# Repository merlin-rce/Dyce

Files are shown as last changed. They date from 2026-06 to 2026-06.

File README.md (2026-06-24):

<div align="center">

DYCE · why roll the same old dice?

**A premium, round, open-source electronic die.** 
Spin the ring, the circular screen
charges up, rolls a number and lands on it. ESP32-S3 · custom PCB · weighted enclosure · USB-C.

[**Live simulator**](https://merlin-rce.tech/Dyce) · [**Gallery**](Media/Gallery.md) · [**Firmware**](Firmware/) · [**Contribute**](CONTRIBUTING.md)

</div>

---

<div align="center">
  Dyce irl demo
</div>

## What it is

- A **round** die that feels like a product,
the screen sits inside a **ring encoder** and stays still while you spin the ring.
- **Custom PCB** (ESP32-S3, GC9A01 round TFT, USB-C, Li-ion charge), hand-soldered, **powered up first try**.
- **100% offline.** Rolls use the ESP32 hardware RNG (`esp_random`) with rejection sampling, so every face is exactly equally likely.
- First real hardware project by a Swiss electronics student, built in the open as a learning log.

## How to Use

- **Spin right** → the ring charges, then rolls and reveals a number.
- **Spin left** → change the odds: `1 in 2 / 5 / 10 / 50 / 99`, plus a **Contact** qr code of the repo.
- **Pause around ⅔** → a little easter egg ;)

Try it all in the **[live simulator](https://merlin-rce.tech/Dyce)**, no hardware needed.

## Build the firmware

C++ / [PlatformIO](https://platformio.org/), target ESP32-S3-WROOM-1.

```bash
git clone https://github.com/merlin-rce/Dyce.git

cd Dyce/Firmware

pio run -t upload      # build & flash
```

Wiring & schematic: [`PCB/`](PCB/) · code overview: [`Firmware/`](Firmware/).

## Print & build the hardware

Everything you need to make your own DYCE is in the repo:

- **3D-printed enclosure** → [`3D Files/`](3D%20Files/) with all the STL parts (body, encoder ring, screen holder, PCB cover, button cap).
- **PCB** → [`PCB/`](PCB/) with the [schematic](PCB/Schematics.pdf) plus ready-to-order **[Gerber & drill files](PCB/Fabrication/)** you can send to any board house (JLCPCB, PCBWay, etc.).

### Edit the 3D model (Onshape)

The full parametric CAD lives on Onshape:

**[Open the DYCE CAD model](https://cad.onshape.com/documents/9054087476b99494dbf8772b/w/43f19220b97c6495800911b1/e/0047a7d77bd93aa77dba2c59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)**

Want to tweak a part or design your own variation? **[Ask me for access](https://github.com/merlin-rce/Dyce/issues)**, then **make your own copy** (Onshape, *Make a copy*) so you can edit freely without touching the original.

## Make it your own

DYCE is **finished, but not closed.** Everything here is open so you can **build one,
tweak it, and make it better.** Flash a different animation, add new odds, rethink the
attract loop, redesign the enclosure, or fork the whole thing into your own gadget.
That's exactly what it's here for. If you make a variation, I'd love to see it.

> **A full step-by-step [Instructables](https://www.instructables.com/) build guide is
> coming soon**, every part, every solder joint, start to finish, so anyone can make
> their own. Watch this repo to catch it when it drops.

## a bit of honesty

quick honest part: im 17 and still a student, and this started as a school project. im a beginner and i learn as i go, thats honestly the whole point of this for me. i put it open source because i genuinely want people to look at it, give me feedback and teach me things, im always down to learn and get better.

the hardware is fully me: the pcb, the schematic, picking the parts, the cad, the soldering and all the debugging that comes with it. pretty proud of that part. the web simulator was mostly built with claude (ai) since my react/html is still basic. for the firmware i use ai to help me too, but as a beginner i really try to understand what im doing and learn from it, not just blindly copy paste.

and if you notice theres barely any commits, its just cause im still new to github and kinda pushed everything at once. still learning that part too

## Contribute

This is a learning project and **feedback / PRs are genuinely welcome**: schematic
nitpicks, firmware cleanups, enclosure ideas, anything. Start with **[CONTRIBUTING.md](CONTRIBUTING.md)**
or open an [issue](https://github.com/merlin-rce/Dyce/issues).

## Status

**Project finished**, built, working, and documented in the open.

| Hardware | Firmware | Enclosure |
|---|---|---|
| Working | Done | Done (could be better) |

## License

Firmware & code: **MIT** (see [`LICENSE`](LICENSE)).
Hardware and docs are intended as **CERN-OHL-S v2** and **CC BY-SA 4.0** respectively.
*To be confirmed before final.*

<div align="center">
  Built in Switzerland by <a href="https://github.com/merlin-rce">@merlin-rce</a> · learning as I go.
</div>

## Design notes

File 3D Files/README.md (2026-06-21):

# DYCE 3D printed parts
<div align="center">
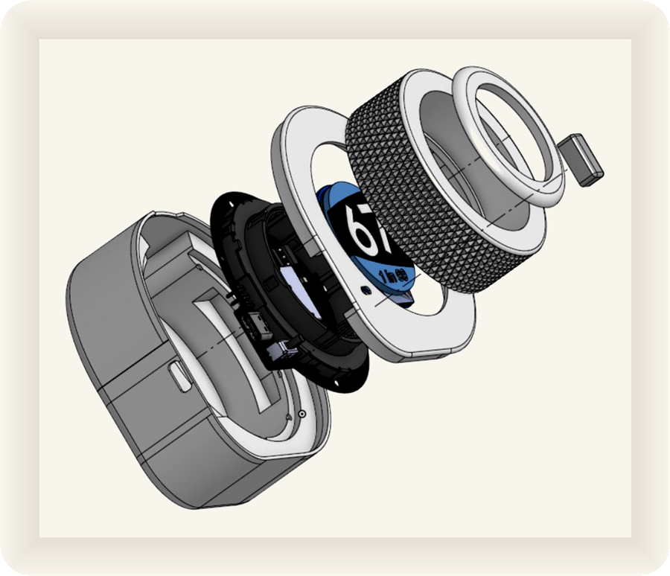
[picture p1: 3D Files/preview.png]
DYCE 3D parts

</div>

---

The full enclosure, ready to print (STL, v5).

| File | Part |
|---|---|
| [`Bottom.stl`](Bottom.stl) | main body / base |
| [`Encoder-ring.stl`](Encoder-ring.stl) | the ring you spin (encoder) |
| [`Screen-holder.stl`](Screen-holder.stl) | holds the round GC9A01 screen |
| [`PCB-cover.stl`](PCB-cover.stl) | cover over the PCB |
| [`Button-cap.stl`](Button-cap.stl) | cap for the side power button |

## Edit the model

These STLs are exported from the parametric CAD on **Onshape**:

**[Open the DYCE CAD model](https://cad.onshape.com/documents/9054087476b99494dbf8772b/w/43f19220b97c6495800911b1/e/0047a7d77bd93aa77dba2c59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)**

To change a part or make a variation, **ask me for access**, then **make your own copy**
(Onshape, *Make a copy*) and edit freely. The original stays untouched.

## Printing

All five parts are FDM-friendly and print without drama, no exotic settings needed.

**Tested print:** I printed the whole set in **matte PLA** on a **Bambu Lab A1**, straight
from **Bambu Studio's standard 0.20 mm quality preset** with no custom tuning, and it came
out clean. PLA (matte looks great) or PETG both work well.

| Setting | What I used |
|---|---|
| Printer | Bambu Lab A1 |
| Material | Matte PLA |
| Profile | Bambu Studio · 0.20 mm Standard (default) |
| Supports | only where overhangs need them |

> **Coming soon on [MakerWorld](https://makerworld.com/)**, ready-to-print profiles,
> one click from your slicer.

Full orientation, support placement and the rest of the assembly will be covered in the
step-by-step **Instructables** build guide (coming soon).

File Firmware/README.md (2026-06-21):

<div align="center">

# DYCE Firmware

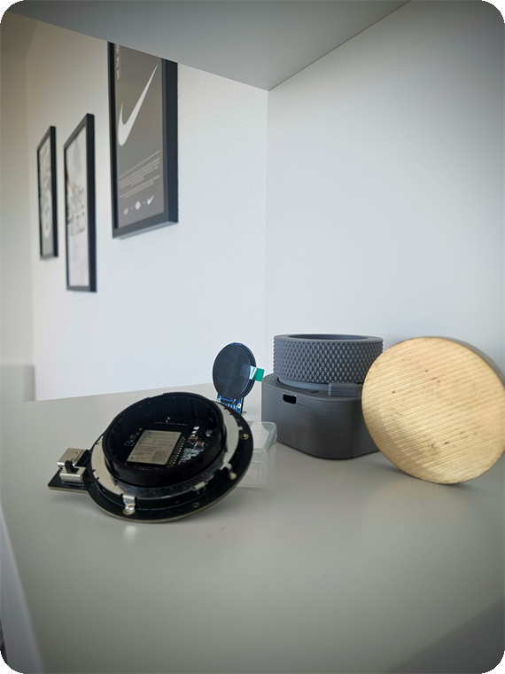
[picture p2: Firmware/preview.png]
DYCE screen


C++ / [PlatformIO](https://platformio.org/) · ESP32-S3-WROOM-1 · GC9A01 round TFT · **100% offline**

</div>

---

## Build & flash

```bash
cd Firmware
pio run -t upload      # build & flash
pio device monitor     # serial @ 115200
```

Display & encoder pins live in [`platformio.ini`](platformio.ini) (TFT_eSPI reads them at compile time).

## Layout

| File | What it does |
|---|---|
| [`src/main.cpp`](src/main.cpp) | setup / loop, wires the encoder to the game |
| [`src/dice.cpp`](src/dice.cpp) | game state machine (intro · attract · charge · reveal) |
| [`src/ui.cpp`](src/ui.cpp) | all rendering on the round screen (sprite buffer) |
| [`src/rng.cpp`](src/rng.cpp) | fair rolls (ESP32 hardware RNG + rejection sampling) |
| [`lib/Encoder_lib/`](lib/Encoder_lib/) | the ring rotary-encoder driver |
| [`include/config.h`](include/config.h) | all the timings, colors and tunables in one place |
| `src/logo.h · icon.h · qr_image.h` | embedded images (intro logo, the "D", contact QR) |

## Make it yours

Most of the feel lives in [`config.h`](include/config.h) and [`ui.cpp`](src/ui.cpp): change
the odds, the colors, the animations or the attract tips and reflash. PRs and forks welcome.

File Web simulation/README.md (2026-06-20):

# DYCE — web simulator

A faithful browser simulator of the DYCE electronic dice, to show the project
without the hardware. It's a 1:1 port of the firmware: the same state machine
(`dice.cpp`) and the same rendering (`ui.cpp`), drawn on a `<canvas>`.

**Live:** intended for `merlin-rce.tech/Dyce`

## Controls
- **Scroll** on the dice = turn the ring encoder
  - scroll **up** → charge the ring & roll
  - scroll **down** → change the difficulty category (… 99 → Contact QR)
  - pause around **2/3** of the ring → unlock the hidden secret (67)
- Click **Power** = the device general switch (on / off)
- (bonus) arrow keys also work

## Run locally
It's a static site — just open `index.html`, or serve the folder:
```bash
python -m http.server      # then visit http://localhost:8000
```

## Deploy
Static hosting. Copy this folder to your web root under `/DYCE`. It needs
internet only for the Montserrat web font (everything else is local).

## Files
| File | Role |
|---|---|
| `index.html` | the page (device mockup + power switch) |
| `style.css` | minimalist styling |
| `app.js` | the simulator (ported game logic + canvas renderer) |
| `assets/logo.png` | the logo (dark theme) |
| `assets/qr.png` | the Contact QR code |

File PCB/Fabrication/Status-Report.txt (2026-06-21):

Output: NC Drill Files
Type  : NC Drill
From  : PCB Document [PCB.PcbDoc]
   Generated File[PCB-RoundHoles.TXT]
   Generated File[PCB-SlotHoles.TXT]
   Generated File[PCB.DRL]
   Generated File[PCB.LDP]
   Generated File[PCB.DRR]

Files Generated   : 5
Documents Printed : 0

Finished Output Generation At 08:49:06 On 02.04.2026

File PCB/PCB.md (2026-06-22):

# DYCE PCB
---

The custom board that runs DYCE: a single round PCB sized to sit behind the screen,
hand-soldered and **powered up first try**. **100% offline**: no Wi-Fi, no radios used
for the game, randomness comes straight from the ESP32 hardware RNG.
<div align="center">
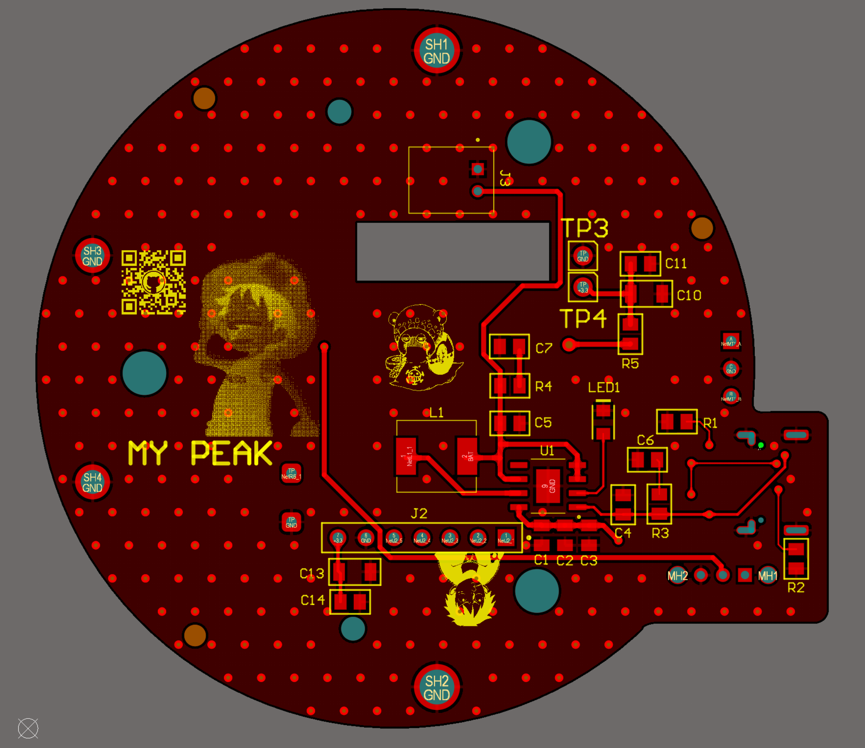
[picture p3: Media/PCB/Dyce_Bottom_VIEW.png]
DYCE Bottom VIEW

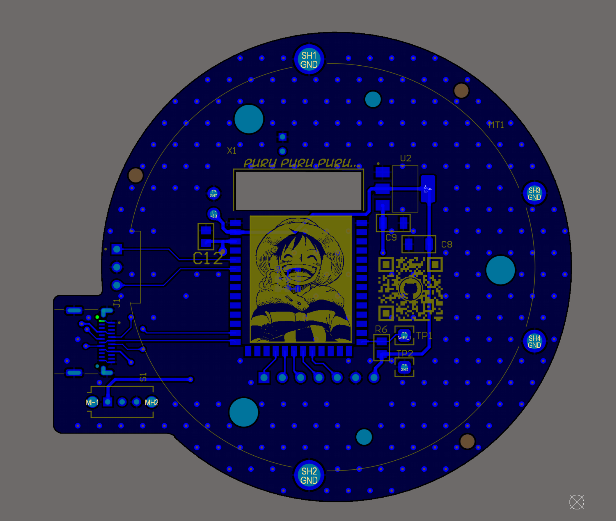
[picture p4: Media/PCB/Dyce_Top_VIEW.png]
DYCE Top VIEW

</div>

## What's on it

- **MCU**: ESP32-S3-WROOM-1 (N16R8, 16 MB flash + 8 MB PSRAM)
- **Display**: GC9A01 1.28″ **round** 240×240 TFT, SPI
- **Input**: ring **rotary encoder** (the screen stays still while you spin the ring)
- **Power**: USB-C, Li-ion charging, side power button

## Pinout (firmware)

These match the firmware. Display pins are set at compile time in
[`../Firmware/platformio.ini`](../Firmware/platformio.ini), the encoder in
[`../Firmware/include/config.h`](../Firmware/include/config.h).

| Signal | GPIO | Notes |
|---|---|---|
| TFT SCLK | 14 | display SPI clock |
| TFT MOSI (SDA) | 13 | display SPI data |
| TFT DC | 12 | data / command |
| TFT CS | 11 | chip select |
| TFT RST | 10 | reset |
| TFT MISO | n/a | unused |
| Encoder A | 6 | `PIN_ENC_A` |
| Encoder B | 5 | `PIN_ENC_B` |

> No backlight pin, the GC9A01 module is driven directly. Flip the encoder direction
> with `ENC_DIR` in `config.h` if it reads backwards.

## Files

- **[`Schematics.pdf`](Schematics.pdf)**: full schematic.
- **[`Fabrication/`](Fabrication/)**: everything a board house needs.
  - `Gerber/`: copper, mask, silk, outline (`.GTL/.GBL/.GTS/.GBS/.GTO/.GBO/.GM`)
  - `Drill/`: NC drill files (round + slot holes)

## Order your own

1. Zip the contents of [`Fabrication/`](Fabrication/) (Gerber + Drill).
2. Upload to any board house: **[JLCPCB](https://jlcpcb.com/)**, **[PCBWay](https://www.pcbway.com/)**, etc.
3. Defaults are fine (1.6 mm, HASL or ENIG). The round outline is in the Gerbers, so no extra setup needed.

A full step-by-step assembly walk-through (board, screen, enclosure) is coming with the
**Instructables** guide. Found an issue or improved the layout?
[Open an issue](https://github.com/merlin-rce/Dyce/issues), schematic nitpicks welcome.

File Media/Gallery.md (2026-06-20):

# Gallery

All the visuals of **DYCE** — 3D renders, the PCB, and build photos.

> Live simulator: **[merlin-rce.tech/Dyce](https://merlin-rce.tech/Dyce)**

## Renders

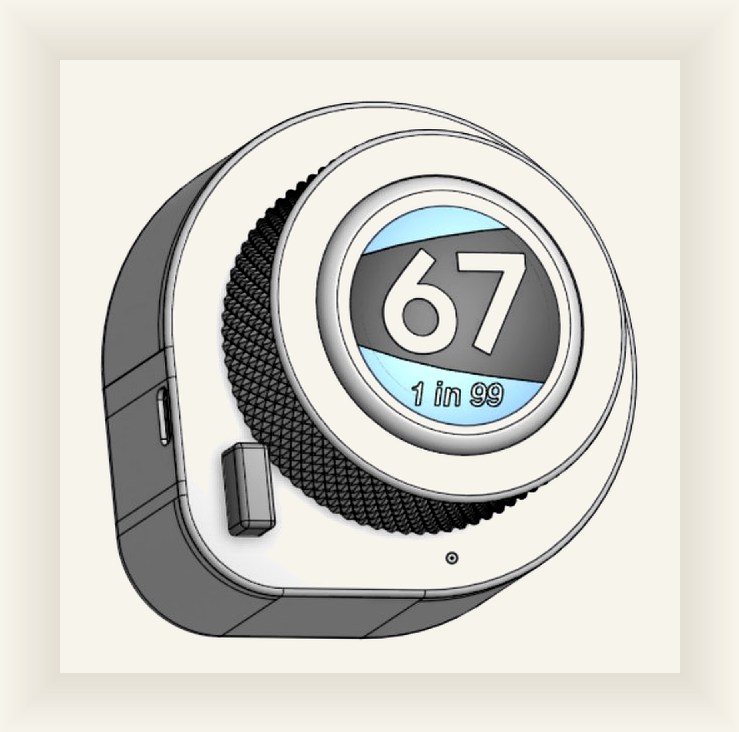
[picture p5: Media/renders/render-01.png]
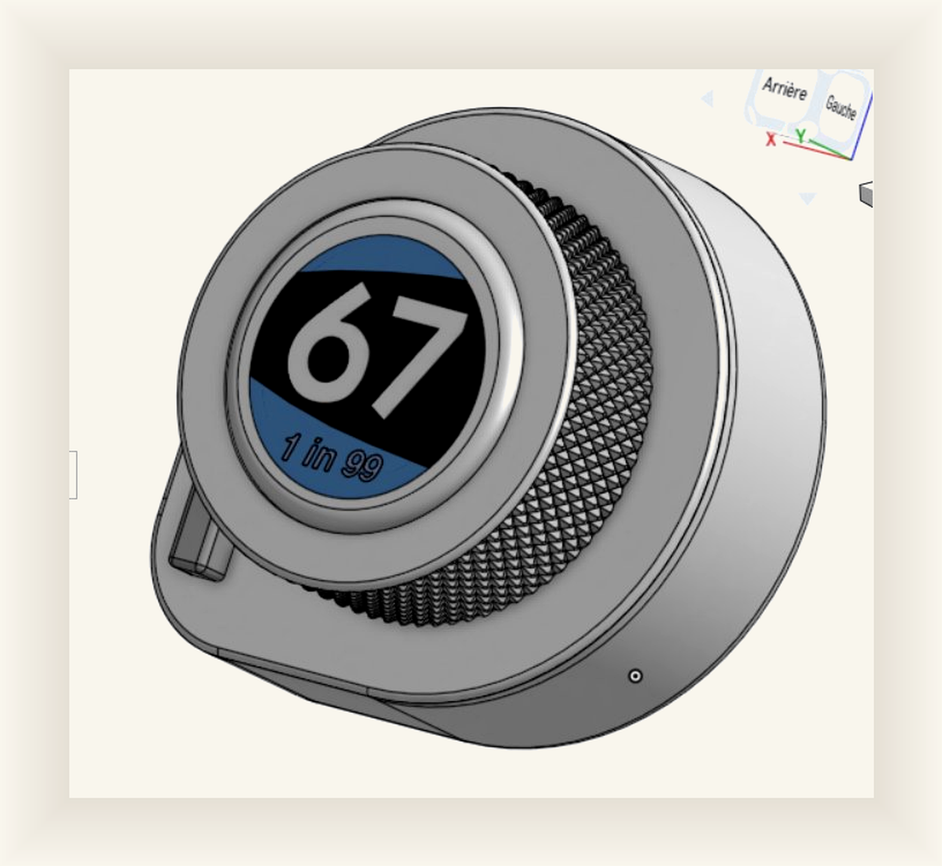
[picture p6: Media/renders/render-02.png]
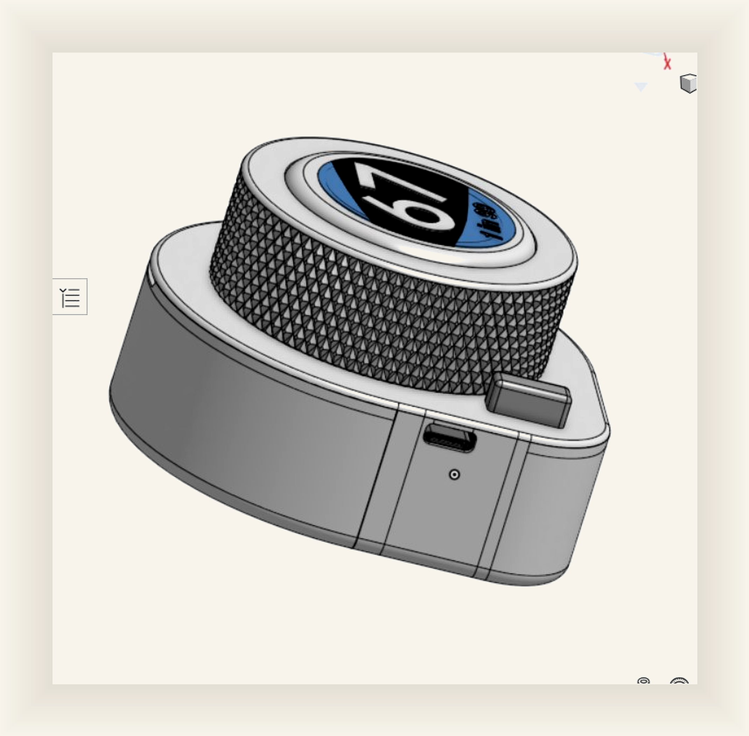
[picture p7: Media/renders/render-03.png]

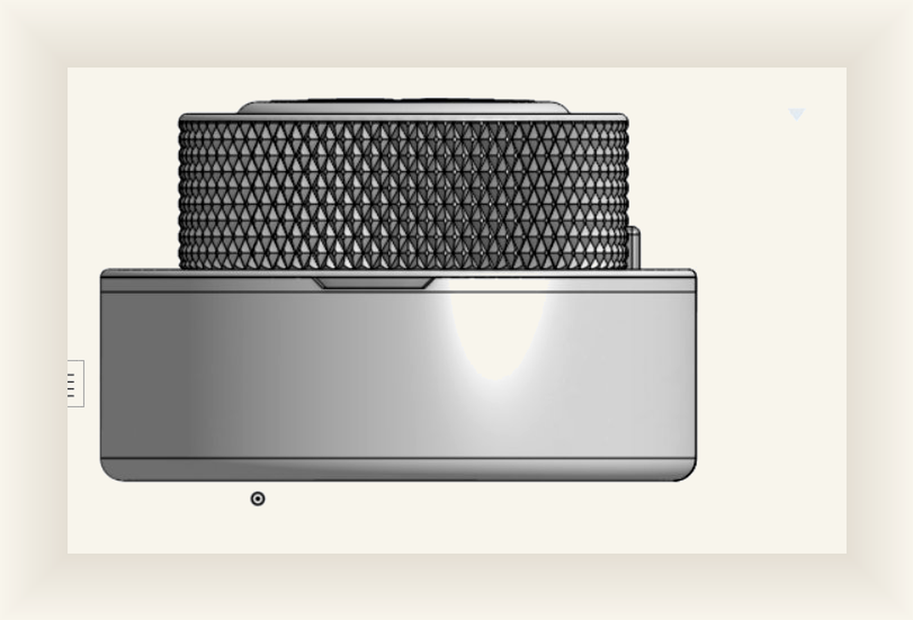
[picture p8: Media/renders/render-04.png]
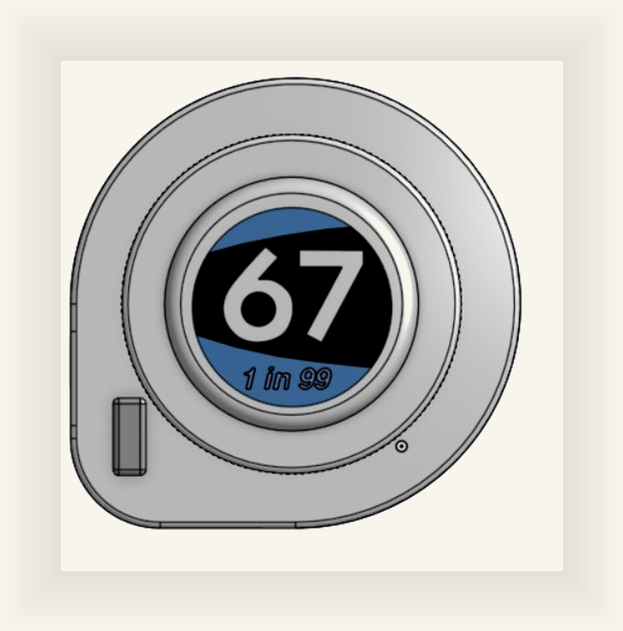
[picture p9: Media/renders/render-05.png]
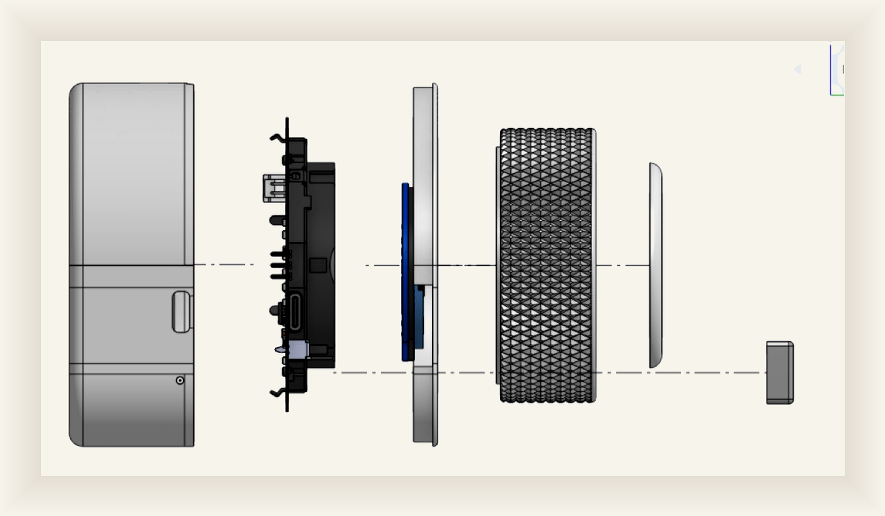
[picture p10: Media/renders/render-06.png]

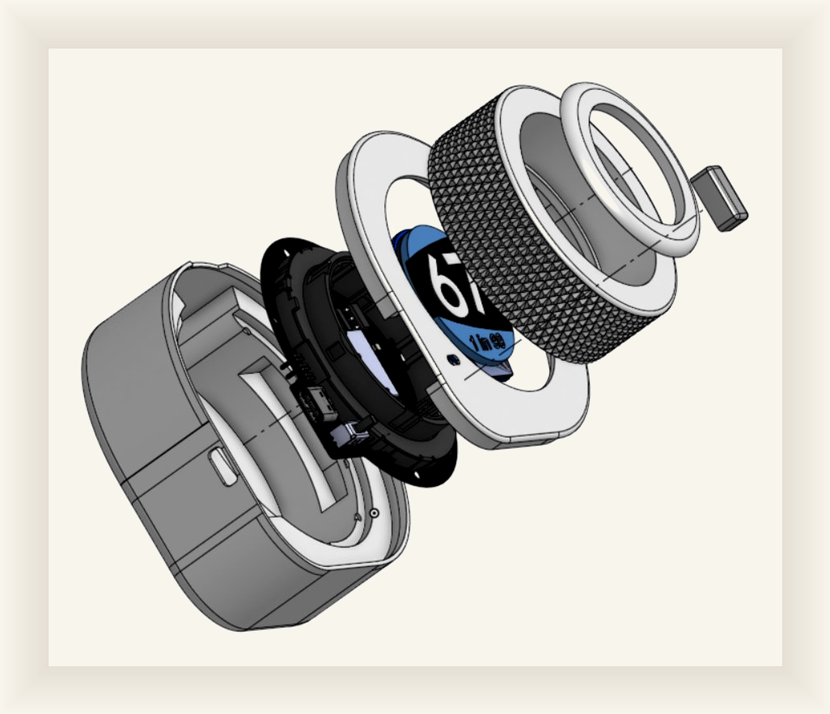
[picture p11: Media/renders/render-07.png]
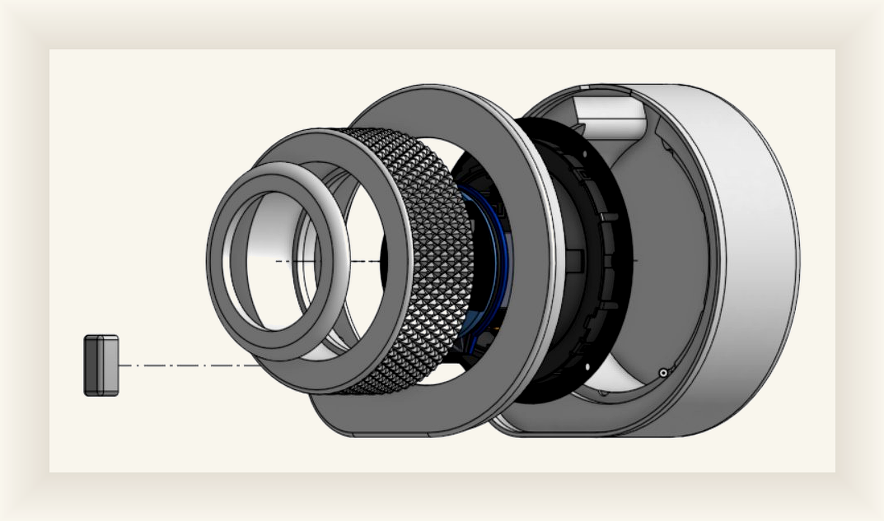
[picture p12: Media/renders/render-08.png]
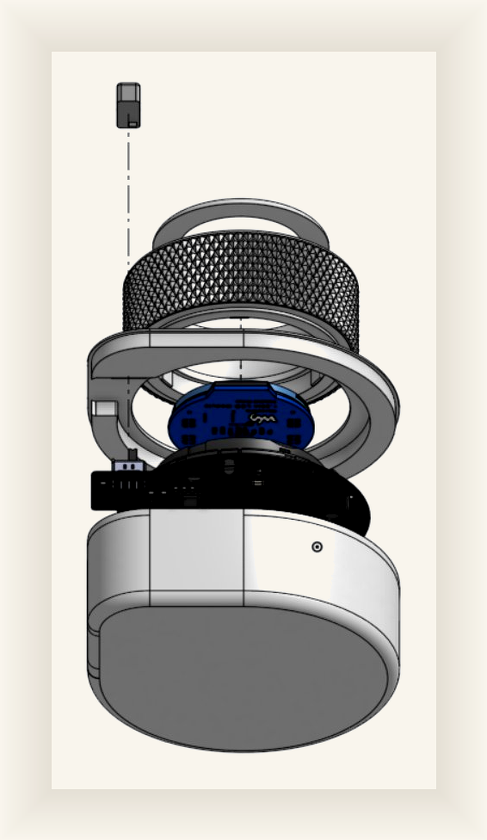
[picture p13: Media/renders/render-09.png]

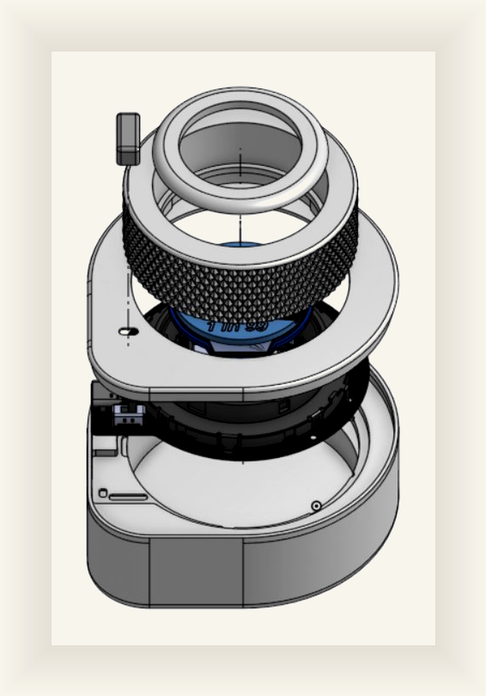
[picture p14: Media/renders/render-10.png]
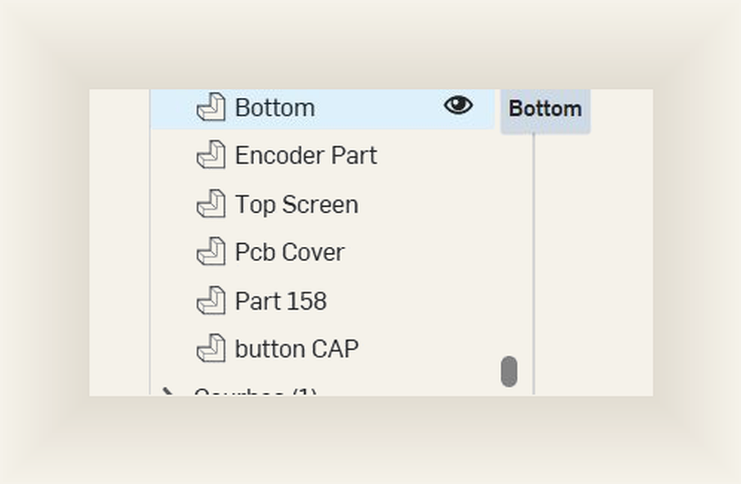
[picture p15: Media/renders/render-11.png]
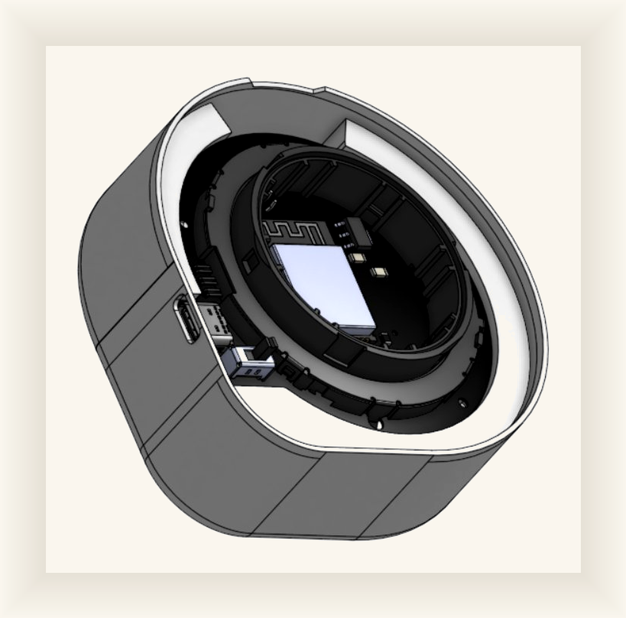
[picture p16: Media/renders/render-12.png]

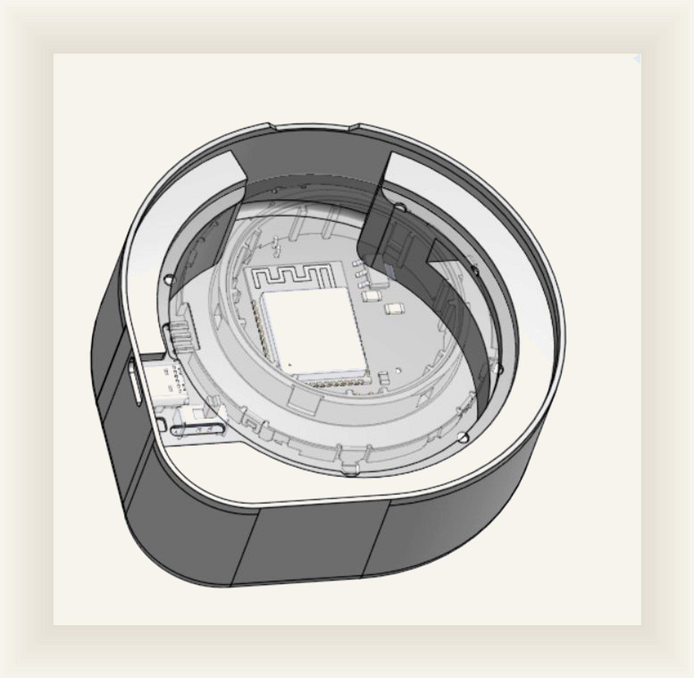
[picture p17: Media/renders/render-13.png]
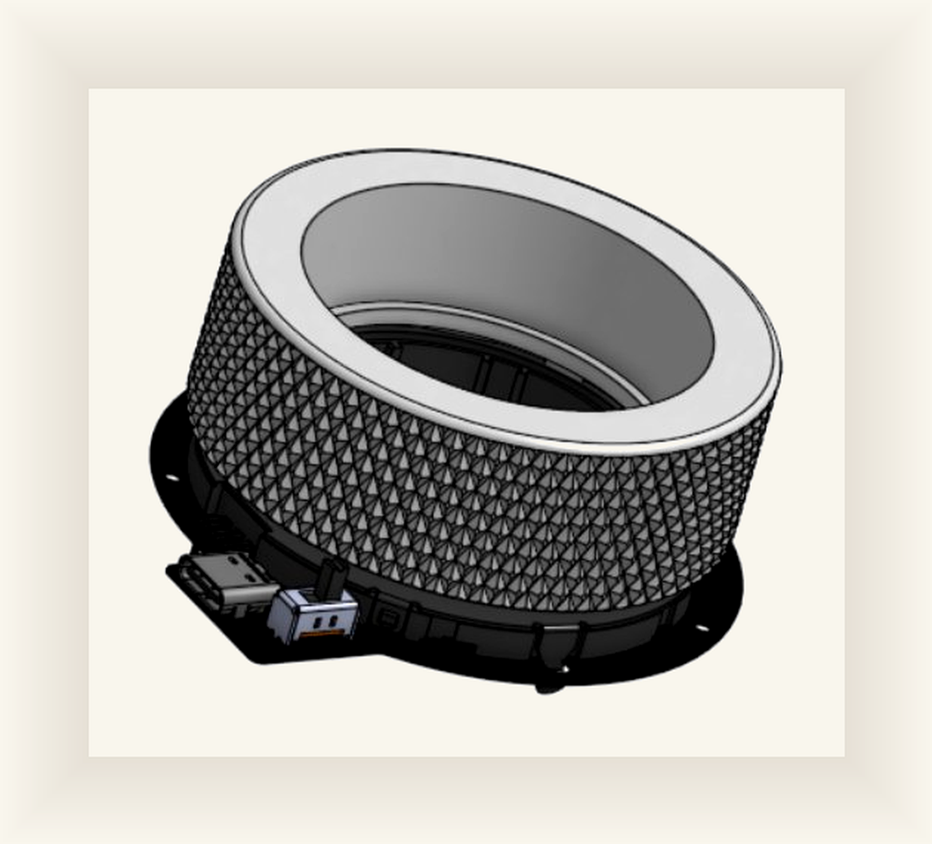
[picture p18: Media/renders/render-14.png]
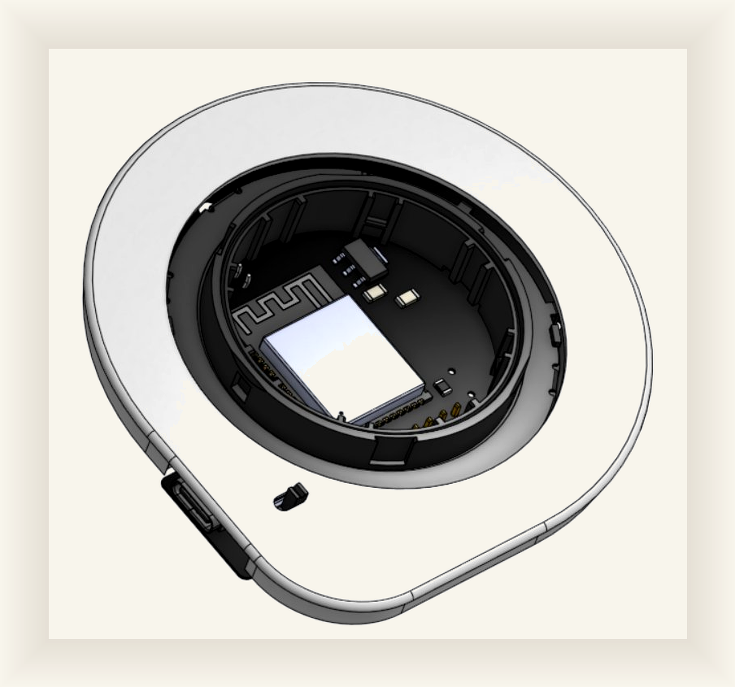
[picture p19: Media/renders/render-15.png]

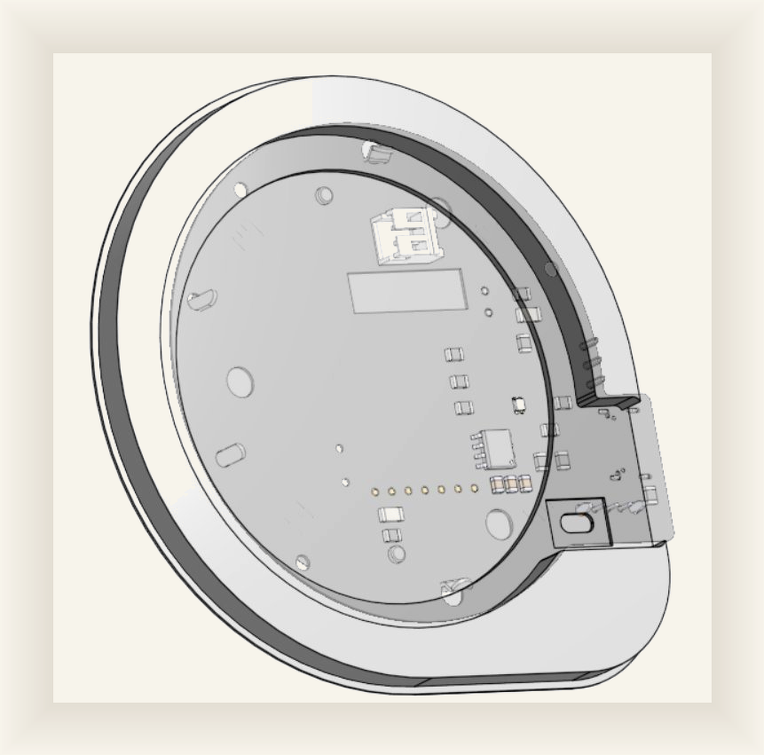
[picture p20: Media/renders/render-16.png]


## PCB

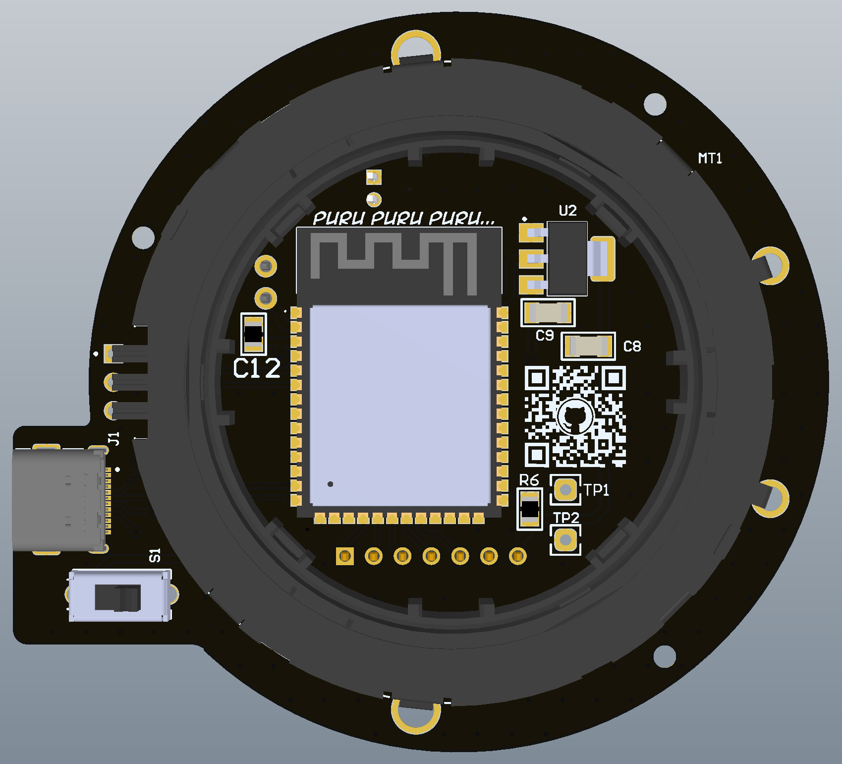
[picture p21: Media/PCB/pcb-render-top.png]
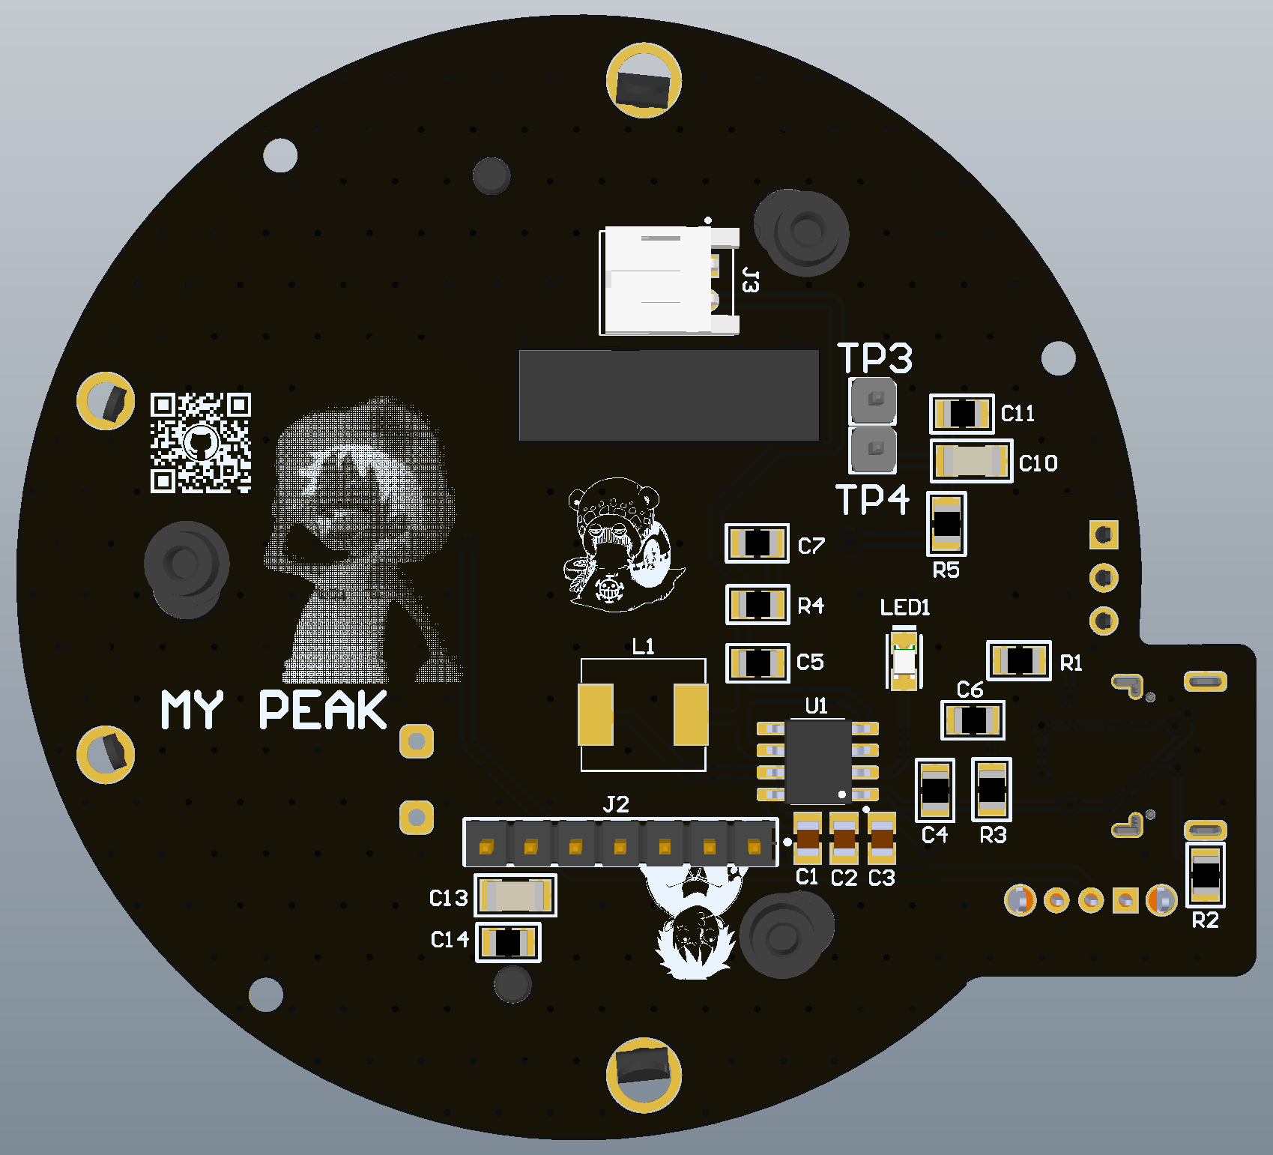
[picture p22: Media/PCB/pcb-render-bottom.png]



## Build log

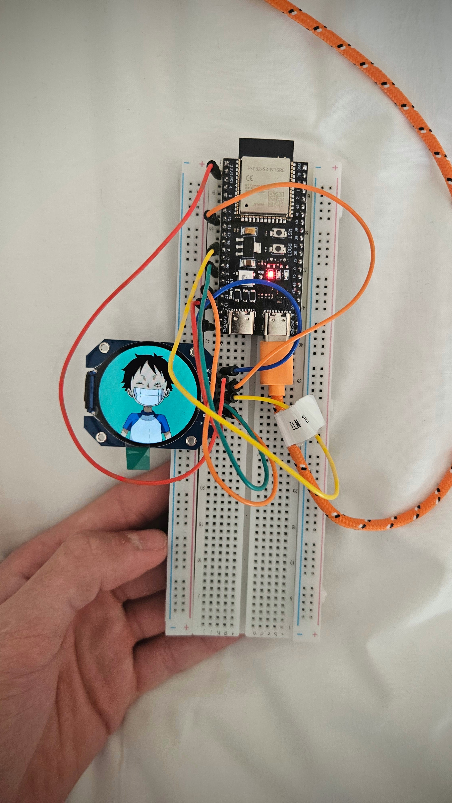
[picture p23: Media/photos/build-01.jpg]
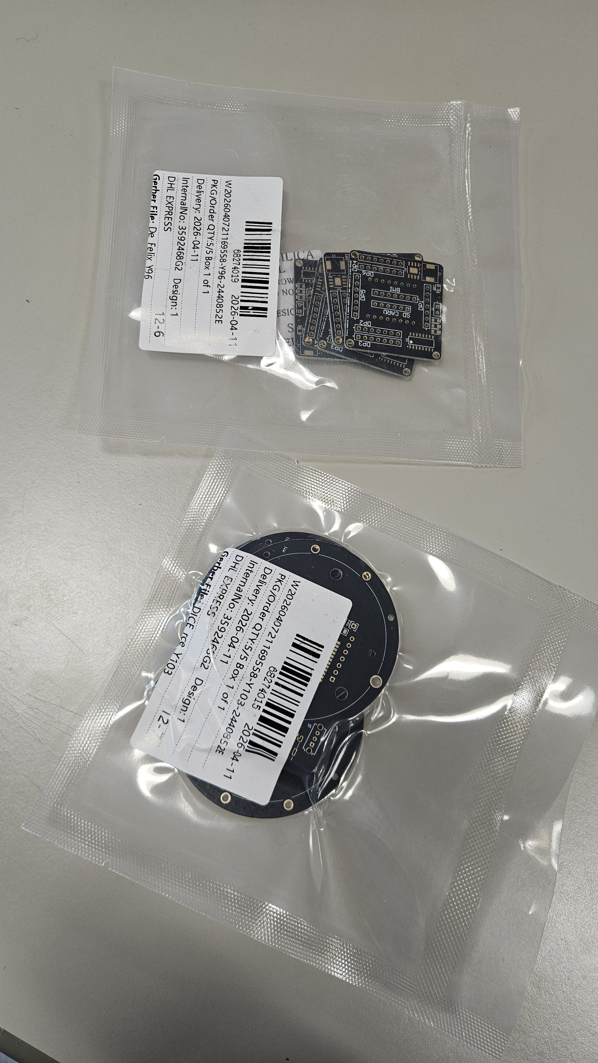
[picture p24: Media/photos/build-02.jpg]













### Clips
- [clip-01.mp4](photos/clip-01.mp4)
- [clip-02.mp4](photos/clip-02.mp4)
- [clip-03.mp4](photos/clip-03.mp4)
- [clip-04.mp4](photos/clip-04.mp4)
- [clip-05.mp4](photos/clip-05.mp4)

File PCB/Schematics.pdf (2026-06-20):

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
File :

Designer : | Reviewer :
Last Edit : | Page :
Project : | Rev :

Power.SchDoc

18.05.2026 1 / 3

1 2
1uH
L1 | 2Ω R4

10uF

C7

10uF

C5

2Ω

R3

10uF

C6

10uF

C4

VIN 1

KEY 5

VOUT | 8
LED1 | 2
LED2 | 3
LED3 | 4
SW | 7
BAT | 6
POWERPAD | 9

U1

IP5306

LED1

GND | GND | GND | GND
GND | BAT
5K1 | BAT

R1

5K1

R2

GND | GND
VIN 3 | VOUT | 2
| VOUT | 4
| GND | 1

U2

MC33269ST-3.3T3G

10uF

C8

GND | GND

10uF

C9

# Charging Module

# LDO Regulator 5V to 3.3V

# USB-C

USB_D- | USB_D+

C3
22uF

C1
22uF

C2
22uF

1

1
2

2

J3

440055-2

GND
BAT
Battery Connector | 2

1 3

S1

General Switch

VBUS_A A4
VBUS_A A9
TXP1 A2
TXN1 A3
CC1 A5
DP1 A6
DN1 A7
SBU1 A8
RXN2 A10
RXP2 A11
GND_A A1
GND_A A12

SHIELD SH1, SH2, SH3, SH4 ⁽SH)

VBUS_B | B4
VBUS_B | B9
RXP1 B11
RXN1 | B10
SBU2 | B8
DN2 | B7
DP2 | B6
CC2 | B5
TXN2 | B3
TXP2 | B2
GND_B | B1
GND_B | B12

J1

2216100001

USB_D+

USB_D+
USB_D-

USB_D-

5v USB-C

5v USB-C

+5

GND

+5

+3.3

D D

C C

B B

A A

Designer : | Reviewer :
Last Edit : | Page :
Project : | Rev :

I_O.SchDoc

18.05.2026 2 / 3

A

A
B

B
C

C

SHIELD SH1
SHIELD SH2
SHIELD SH3
SHIELD SH4

MT1

Encodeur RING-TH
GND

ENC_B

ENC_A

# Ring Encodeur

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
TSW-107-07-G-S

# 1.28" TFT Screen

RST

CS

DC

SDA

SCL

GND

C14
100nF
GND GND

C13
10uF

+3.3

TP3

TP4

GND

+3.3

D D

C C

B B

A A

Designer : | Reviewer :
Last Edit : | Page :
Project : | Rev :

Esp32.SchDoc

18.05.2026 3 / 3

3V3 2
GND

EN 3

IO21 23
IO35 28
IO36 29
IO37 30
IO38 31
IO39 32
IO40 33
IO41 34
IO42 35
IO45 26
IO46 16
IO47 24
IO48 25
TXD0 37
RXD0 36
IO0 | 27
IO1 | 39
IO2 | 38
IO3 | 15
IO4 | 4
IO5 | 5
IO6 | 6
IO7 | 7
IO8 | 12
IO9 | 17
IO10 | 18
IO11 | 19
IO12 | 20
IO13 | 21
IO14 | 22
IO15 | 8
IO16 | 9
IO17 | 10
IO18 | 11
IO19 | 13
IO20 | 14

X1

ESP32-S3-WROOM-1-N16R8

GND

C10
10uF

R5

R_0805_5K10

USB_D-USB_D+

C11
100nF

ENC_B
ENC_A

RST
CS
DC
SDA
SCL

R6

R_0805_10K_0.125W

TP1

TP2

GND

C12

C_0805_1u00_X7R_16V

+3.3
+3.3

# ESP32-S3 Wroom

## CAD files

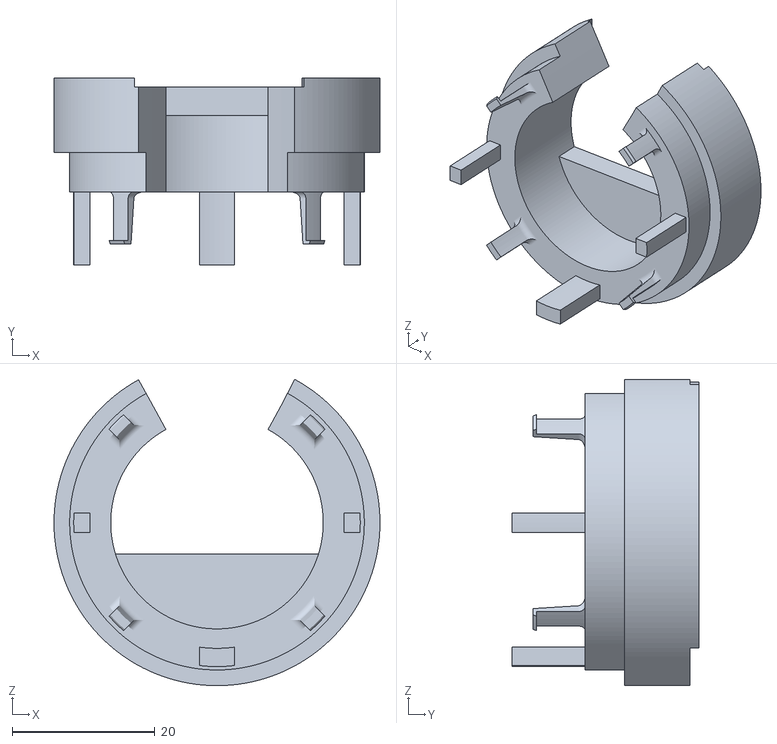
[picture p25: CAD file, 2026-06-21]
3D Files/Screen-holder.stl
45.7 x 26.3 x 43.0

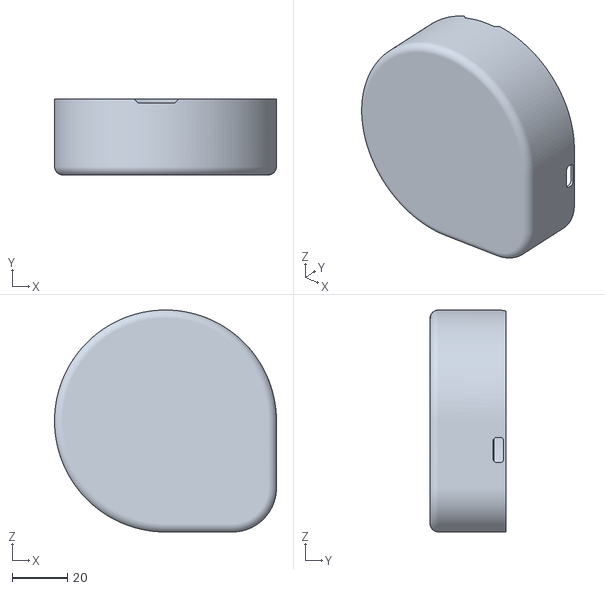
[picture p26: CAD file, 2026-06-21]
3D Files/Bottom.stl
80.5 x 27.5 x 80.5

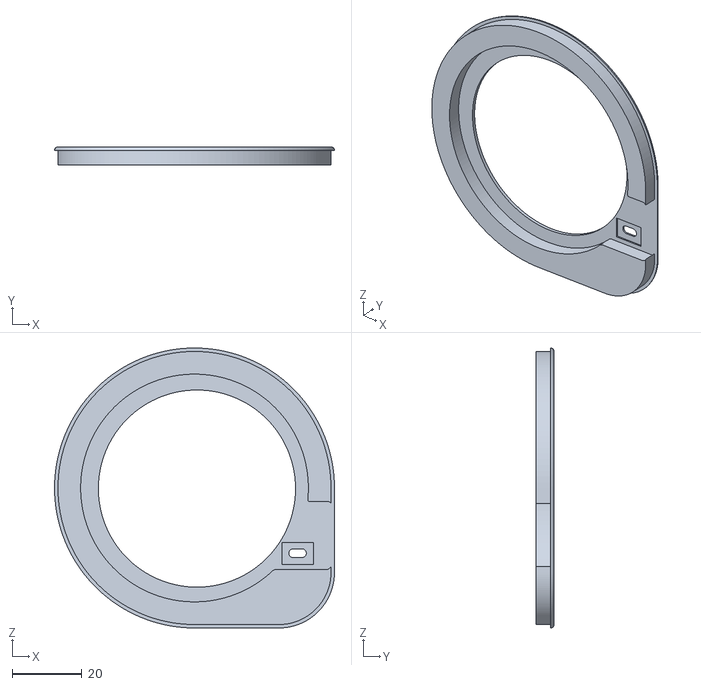
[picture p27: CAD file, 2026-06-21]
3D Files/PCB-cover.stl
80.5 x 5.26 x 80.5

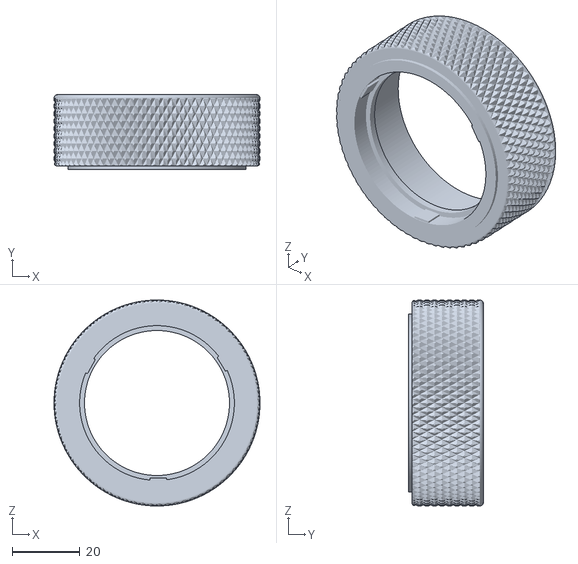
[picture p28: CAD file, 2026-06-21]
3D Files/Encoder-ring.stl
60.7 x 22.0 x 60.7

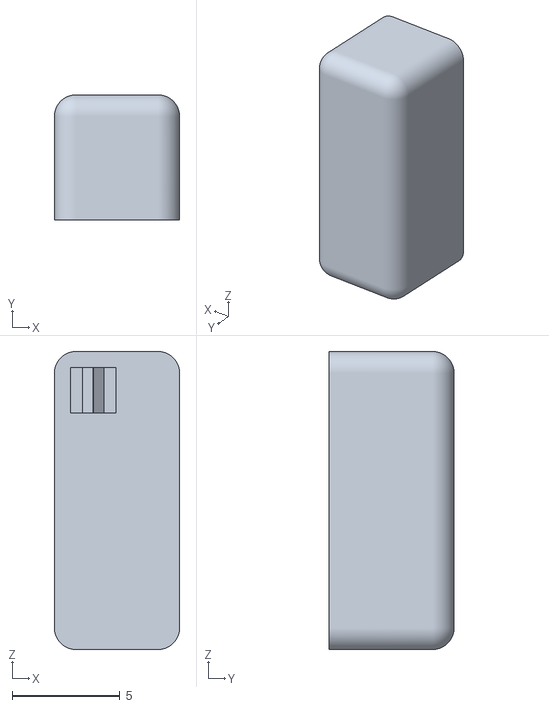
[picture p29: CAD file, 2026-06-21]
3D Files/Button-cap.stl
5.80 x 5.80 x 13.8

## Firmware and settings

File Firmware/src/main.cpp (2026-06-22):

#include <Arduino.h>
#include <Encoder.h>
#include "config.h"
#include "rng.h"
#include "ui.h"
#include "dice.h"

// ===== DYCE =====
// Charge ring : you spin to fill the ring, at the top it rolls a number.
// Other way : changes the rarity N. Pause around 2/3 : arms a special number.
// Everything is non-blocking (millis), 100% offline.

Encoder enc(PIN_ENC_A, PIN_ENC_B);   // ring encoder

void setup() {
    Serial.begin(115200);     // hardware randomness (esp_random)
    ui_begin(SCREEN_ROTATION);       // screen + fullscreen sprite
    enc.begin();
    dice_begin();     // first roll + intro
}

void loop() {
    int sens = enc.read() * ENC_DIR;
    if (sens != 0) dice_input(sens);

    static uint32_t t = 0;
    if (millis() - t >= FRAME_MS) {
        t = millis();
        dice_update();
        ui_draw(dice_view());
    }
}

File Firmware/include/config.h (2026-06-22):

#pragma once

// ===== DYCE settings =====
//Screen rotation (0, 1, 2, 3) : 0 = portrait, 1 = landscape, 2 = portrait flipped, 3 = landscape flipped
#define SCREEN_ROTATION 0

// Encoder pins
#define PIN_ENC_A 6
#define PIN_ENC_B 5
#define ENC_DIR   1        // turn direction (-1 to flip)

// "1 in N" categories (counter-clockwise to change). After the last value
// comes the "Contact" category (index = N_COUNT) that shows a QR code.
static const int N_VALUES[] = { 2, 5, 10, 50, 99 };
static const int N_COUNT    = 5;
#define N_START 1          // starts on the 5

// Ring fill : big steps at the bottom, small at the top -> few notches
#define STEP_MAX_INC 28
#define STEP_MIN_INC 10
#define FILL_SPEED   8     // shown fill speed
#define FRAME_MS     33    // refresh (~30 fps)
#define COOLDOWN_MS  250   // small delay after a roll (spam ok, but not too much)

// Reveal : anim then the number stays a bit, then it clears
#define REVEAL_MS  2500

// Secret : stop around 2/3 -> lands on 67
#define SECRET_LO 55
#define SECRET_HI 80
#define SECRET_MS 1500

// Boot intro + idle mode
#define INTRO_MS   4500    // intro movie, paced
#define ATTRACT_MS 10000   // without touching anything -> clears the number, back to the tips
#define FADE_MS    900     // soft fade-in of the tips
#define ATTRACT_OUT_MS 250 // fast fade-out of the tips when you start turning
#define FIRST_MS   8000    // the very 1st tip stays longer
#define HEHE_MS    6000    // the secret 67 stays shown this long then disappears

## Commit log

2026-06-20 DYCE - initial public release
    A premium, round, open-source electronic die.
    ESP32-S3 firmware (100% offline, hardware RNG), an interactive web
    simulator, the custom PCB and media. No network code, no secrets.
2026-06-21 Add 3D files, PCB fabrication & docs; reorganize repo
    - Rename Dyce/ -> "Web simulation/" and redesign the simulator (navy
    logo-shaped device, spinning encoder ring, Google Sans, refined power button)
    - Add "3D Files/" with STL enclosure parts + README (print notes, Onshape)
    - Flatten PCB exports into PCB/Fabrication/; write PCB.md
    - README: "Print & build the hardware" + Onshape CAD link; rounded brand logo;
    cleaner styling
    - Add Firmware/README.md; firmware UI tweaks
    - Update CONTRIBUTING repo layout
    [Bottom.stl, Button-cap.stl, Encoder-ring.stl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]
2026-06-22 adding Dyce PCB view
2026-06-22 Add pcb image for pcb review
